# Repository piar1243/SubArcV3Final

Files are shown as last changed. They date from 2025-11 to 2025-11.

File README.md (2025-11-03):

Welcome to the repository for SubArc: An Inexpensive, High Resolution, Open Source, Absolute Magnetic Rotary Encoder!

In this repository, there are the files for the 3D models of the most recent SubArc PCB and Calibration Stand version. There are the SubArc python executable programs and the microcontroller (Arduino standard) code. Additionally, a specification sheet, a mounting tutorial, and other in-depth documentation are also listed.

At this time, SubArc is still under development. That being said, the current SubArc version does output 20 bit resolution at under 150 arc seconds of average accuracy, and can be vigilantly used for low-speed applications. 

The following improvements are being made to release an initial beta-version of SubArc (with the goal being by March 2026):

1) Fix occasional accuracy spike bugs
2) Increase position calibration file search algorithm efficiency
3) Increase sampling rate to 5000 Hz with updated hall sensor array
4) Create through-bore version for easy mounting on machinery

Once these improvements are made and SubArc properly functions embedded on precision machinery technology, SubArc will release into its V1 beta version and this repository will be linked and popularized.

If you would like to build your own alpha version SubArc and need assistance, or you would like to collaborate on speeding up the development to the initial V1 beta version, feel free to contact me at: franklucci636@gmail.com

This work is provisional-patent protected to ensure no one attempts to patent and close source this encoder. All current and future work will continue to be open source under the MIT license.

Current SubArc specification details:

You can customize the SubArc ring and readhead in your PCB software to change the resolution and accuracy

Standard resolution is 20-bits, with an 8mm bore, 55mm diameter, 100 magnets, and 6 hall sensors

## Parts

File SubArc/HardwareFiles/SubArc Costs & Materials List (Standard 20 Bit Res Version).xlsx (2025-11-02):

Materials |  | 1 UNIT IN <100 COST | TOTAL | 1 UNIT IN 100 COST | TOTAL | 1 UNIT IN 1000 COST | TOTAL | 1 UNIT IN 10000 COST | TOTAL | Calibration Stand Cost
1.25mm JST | 1 | $0.08 | $0.08 | $0.07 | $0.07 | $0.06 | $0.06 | $0.05 | $0.05 | RLS AksIM-2 E2019P Interface for SPI | $286.48
TMP117 | 1 | $1.91 | $1.91 | $1.58 | $1.58 | $1.39 | $1.39 | $1.28 | $1.28 | RLS AksIM-2 Encoder Readhead | $205.81
MLX90393SLW-ABA | 6 | $1.65 | $9.90 | $1.60 | $9.60 | $1.42 | $8.52 | $1.32 | $7.90 | RLS AksIM-2 Encoder Magnetic Ring | $212.91
1.25mm JST female | 1 | $0.41 | $0.41 | $0.29 | $0.29 | $0.25 | $0.25 | $0.21 | $0.21 | RLS aksIM-2 Absolute Magnetic Encoder ACC049 Cable Assembly | $13.02
PCB Way 10pc 100*100mm | 1 | $0.50 | $0.50 | $0.50 | $0.50 | $0.50 | $0.50 | $0.50 | $0.50 | Polylactic acid (PLA) filament 1kg | $18.99
1206 3.2*1.6mm SMD LED | 1 | $0.04 | $0.04 | $0.04 | $0.04 | $0.04 | $0.04 | $0.04 | $0.04 | DM542T Stepper Driver | $28.99
Samsung CAP CER 0.1UF 10V 0402 | 13 | $0.01 | $0.07 | $0.003 | $0.04 | $0.0025 | $0.03 | $0.0025 | $0.03 | M2-6 Threaded Heated Inserts & Screws <$10 | $10
RES 10K Ω 1/16W 0402 | 21 | $0.01 | $0.27 | $0.00408 | $0.09 | $0.00152 | $0.03 | $0.00134 | $0.03 | 2A, 48mm Nema 17 Stepper Motor | $13.99
CAP CER 10UF 10V 0805 | 1 | $0.04 | $0.04 | $0.03 | $0.03 | $0.03 | $0.03 | $0.02 | $0.02 | 100:1 Gearbox, 20 arc-min Backlash | $62.00
TI TCA9548APWR | 1 | $0.85 | $0.85 | $0.68 | $0.68 | $0.59 | $0.59 | $0.54 | $0.54 | ESP32 Microcontroller | $9.99
2pc 8mm flange coupling | 1 | $4.09 | $4.09 | $2 | $2 | $2 | $2 | $2 | $2 | 8*150mm h8 tolerance steel shafts | $8.99
1/32in N52 magnet (200pc) | 1 | $3.60 | $3.60 | $2.52 | $2.52 | $2.52 | $2.52 | $2.52 | $2.52 | 8mm ⌀ precision rigid clamp on coupling | $9.99
 |  |  | 0 |  | 0 |  | 0 |  | 0 | 20mm M4 standoff | $6.99
10pc jumper wire | 1 | $0.59 | $0.59 | $0.59 | $0.59 | $0.59 | $0.59 | $0.59 | $0.59 | 4pc F698ZZ 8mm Bore Flange bearing | $7.99
AS5600 Subdivider | 1 | $2.50 | $2.50 | $2.04 | $2.04 | $1.55 | $1.55 | $1.46 | $1.46 |  | $896.14
Total (Inexpensive Encoder): |  |  | $24.84 |  | $20.05 |  | $18.09 |  | $17.16
Magnetic Ring

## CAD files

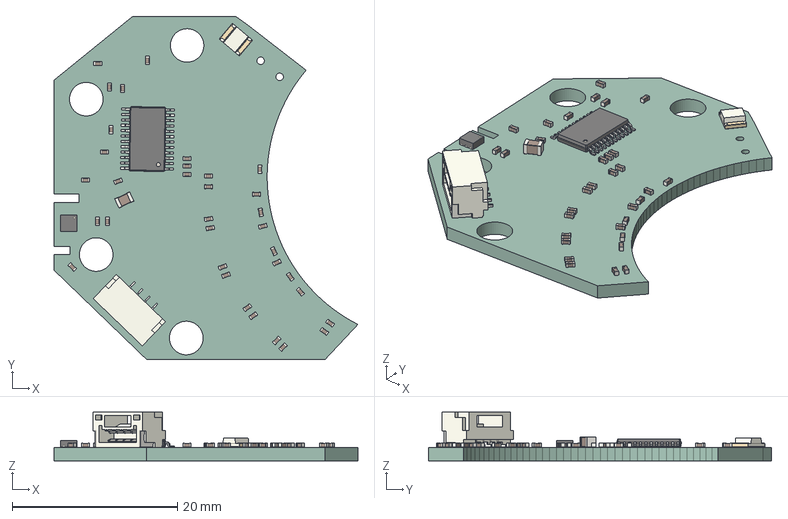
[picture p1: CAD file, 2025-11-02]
SubArc/HardwareFiles/SubArc&CalibrationStandCAD/SubArcModel.step
36.8 x 41.5 x 5.89 mm
C_0402_1005Metric_1 x 34
WSON_6_1EP_2x2mm_P065mm_EP1x16mm
JST_SM04B_GHS_TB
C_0805_2012Metric_1
TSSOP_24_44x78mm_P065mm
LED_1210_3225Metric_1
_autosave-SubArcV3 PCB

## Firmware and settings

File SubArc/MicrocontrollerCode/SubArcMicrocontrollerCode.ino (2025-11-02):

 #include <Wire.h>
#include "Adafruit_MLX90393.h"
#define stepPin 6 //defined arduino pins for rotating calibration stand stepper motor
#define dirPin 7
Adafruit_MLX90393 sensor = Adafruit_MLX90393();//uses adafruit MLX90393 sensor library to pull magnetic field readings from each sensor
#define MLX90393_CS 10 //cs pin on arduino
#include <Adafruit_TMP117.h> //uses the adafruit TMP117 sensor library and the adafruit sensor library
#include <Adafruit_Sensor.h>

Adafruit_TMP117  tmp117; //defines the tmp117 temperature sensor
double temper = 0;
int ill = 101;
String t_holder = "[24.5]"; //temperatures
String e_holder = "[0.1]";

float mag1 = 0;
float mag2 = 0;
int magnetStatus = 0; //magnet status of AS5600
 
int lowbyte; //AS5600 angle bits 7:0
word highbyte; //AS5600 angle bits 7:0 11:8
int rawAngle; //AS5600 angle out of 4096 (12 bits)
float degAngle; //AS5600 12 bit angle output out of 360

float mag_comp_val_x = 0;
float mag_comp_val_y = 0;
float mag_comp_val_z = 0;

float field_x_ca_val = 0;
float field_y_ca_val = 0;
float field_z_ca_val = 0;

void setup(void)
{
  pinMode(stepPin,OUTPUT); //activate pins
  pinMode(dirPin,OUTPUT);
  Serial.begin(115200); //begin serial

  Wire.begin(); //begin wire
  Wire.setClock(800000L); //set the clock cycle to the fastest possible cycle time


  TCA9548A(6); //switch to warmup
  
  while (!Serial) delay(10);  //will pause to wait for the Serial console to open

  if (!tmp117.begin()) { //initializes the TMP117 temperature sensor
    Serial.println("TMP117 disconnect");
    while (1) { delay(10); }
  }
  Serial.println("TMP117"); //printing to show that the sensor was intitialized

  
  
  TCA9548A(1); //switch to hall sensor 1
  Serial.println("active");

  while (!Serial) //wait for serial again to ensure no bugs
    delay(10);

   
  if (! sensor.begin_I2C(0x0c)) { //communicates to the standard MLX90393 (will change depending on which MLX90393 version you get)
    Serial.println("MLX90393 disconnect");
    while (1) { delay(10); }
  }
  Serial.println("MLX90393"); //indicates the MLX90393 has been activated and found
for (int i = 0; i < 6; i++){ //loops through all the different MLX90393 and defines their gain to the max, sets to max resolution, and most time effective and accurate sampling rate
  
  TCA9548A(i); //sets the multiplexer to the specific MLX90393 sensor
  
  sensor.setGain(MLX90393_GAIN_5X); //sets the MLX90393 gain to the max for best resolution
  // You can check the gain too
  Serial.print("Gain: ");
  switch (sensor.getGain()) { //defines the different gains available (pulled from the Adafruit libraries)
    case MLX90393_GAIN_1X: Serial.println("1 x"); break;
    case MLX90393_GAIN_1_33X: Serial.println("1.33 x"); break;
    case MLX90393_GAIN_1_67X: Serial.println("1.67 x"); break;
    case MLX90393_GAIN_2X: Serial.println("2 x"); break;
    case MLX90393_GAIN_2_5X: Serial.println("2.5 x"); break;
    case MLX90393_GAIN_3X: Serial.println("3 x"); break;
    case MLX90393_GAIN_4X: Serial.println("4 x"); break;
    case MLX90393_GAIN_5X: Serial.println("5 x"); break;
  }
.
  sensor.setResolution(MLX90393_X, MLX90393_RES_17); //sets the sensor resolution for each axis, goes to the max
  sensor.setResolution(MLX90393_Y, MLX90393_RES_17);
  sensor.setResolution(MLX90393_Z, MLX90393_RES_16);

  sensor.setOversampling(MLX90393_OSR_1); //sets oversampling rate to 1 so SubArc sampling time remains high

  sensor.setFilter(MLX90393_FILTER_5); //get the highest digital filter setting from MLX90393 for high accuracy at high resolution

}

}

void loop(void) {

  if (Serial.available() > 0) { //reads incoming byte from the python script
    char incomingByte = Serial.read();

  

  TCA9548A(6); //switches to the temperature sensor
  sensors_event_t temp; // create an empty event to be filled (from adafruit library)
  tmp117.getEvent(&temp); //fill the empty event object with the current measurements
  
  checkMagnetPresence(); //checks if the AS5600 is there, sends error if not
  ReadRawAngle(); //reads subdividing AS5600 position
  mag1 = degAngle; //sets the mag1 reading to the AS5600 position
   
  TCA9548A(5); // moves to the 5th MLX90393 (the Bexternal sensor)
  float x, y, z; //defines axis magnetic fields
   
  if (sensor.readData(&x, &y, &z)) {} //checks if sensor read data (from adafruit library)
  else {
    Serial.println("Unable to read XYZ data from the sensor.");
  }
  sensors_event_t event;
  sensor.getEvent(&event);
  mag_comp_val_x = event.magnetic.x; //sets the magnetic values to variables to subtract from regular MLX90393 readings
  mag_comp_val_y = event.magnetic.y;
  mag_comp_val_z = event.magnetic.z;
   
  
  for (int i = 0; i < 5; i++){ //loops through the MLX90393 array
    TCA9548A(i);
    float x, y, z; //defines the axis magnetic fields

    if (sensor.readData(&x, &y, &z)) {} //checks if sensor read data (from adafruit library)
    else {
        Serial.println("Unable to read XYZ data from the sensor.");
    }

    sensors_event_t event; // create an empty event to be filled (from adafruit library)
    sensor.getEvent(&event); //fill the empty event object with the current measurements
    Serial.print(String(i) + ", "); //print which hall sensor in the array your on in serial
    //Serial.print("X: "); 
  // Serial.print("["); 
  //all these values are picked up by python script when activited in the Serial communication protocol
    Serial.print(trun(int(event.magnetic.x - mag_comp_val_x + field_x_ca_val))); //prints the true X axis magnetic field for that hall sensor in the array
    Serial.print(", "); 
    Serial.print(int(trun(event.magnetic.y - mag_comp_val_y + field_y_ca_val))); //prints the true Y axis magnetic field for that hall sensor in the array
    Serial.print(", "); 
    Serial.print(int(trun(event.magnetic.z - mag_comp_val_z + field_z_ca_val))); //prints the true Z axis magnetic field for that hall sensor in the array
    Serial.print(", "); 

  // Serial.print("]");
    if (i < 4){
  //  Serial.print(", "); 
    }
  //Serial.println(temper);

    
  }
   
  // Serial.print("]");
 //  Serial.print("]");
 //  Serial.println("]");
   //Serial.println();
  Serial.print(degAngle); // prints the AS5600 angle
  Serial.print(", "); //adds the , because the data needs to be formatted correctly for the python script
  Serial.println(temp.temperature); //finally adds the temperature add the end of the string

if (incomingByte == 'b'){ //backwards stepper increment is B sending from the python script

   digitalWrite(dirPin, LOW);
   digitalWrite(stepPin,HIGH); 
   delayMicroseconds(20000);
   digitalWrite(stepPin,LOW); 
   delayMicroseconds(20000);

  
}

if (incomingByte == 'c'){ //forwards stepper increment is C sending from the python script

   digitalWrite(dirPin, HIGH);
   digitalWrite(dirPin, HIGH);
   digitalWrite(stepPin,HIGH);    
   delayMicroseconds(20000);
   digitalWrite(stepPin,LOW); 
   delayMicroseconds(20000);

  
}
}
}

void TCA9548A(uint8_t bus) //function to switch the sensors with the same I2C going to the multiplexer, function from adafruit
{
  Wire.beginTransmission(0x70); //TCA9548A address is 0x70
  Wire.write(1 << bus); //sending byte selects the number bus
  Wire.endTransmission();
}

int trun(int number) { //truncate function
    return (number / 10);
}


void ReadRawAngle() //reads the raw angle from the AS5600 (library function from curious scientist as5600 tutorial)
{ 

  Wire.beginTransmission(0x36); //connect to the sensor
  Wire.write(0x0D); //figure 21 - register map: Raw angle (7:0)
  Wire.endTransmission(); //end transmission
  Wire.requestFrom(0x36, 1); //request from the sensor
  
  while(Wire.available() == 0); //wait until it becomes available 
  lowbyte = Wire.read(); //Reading the data after the request
 
  Wire.beginTransmission(0x36);
  Wire.write(0x0C);
  Wire.endTransmission();
  Wire.requestFrom(0x36, 1);
  while(Wire.available() == 0);  
  highbyte = Wire.read();
  highbyte = highbyte << 8; //shifting to left
  rawAngle = highbyte | lowbyte; //int is 16 bits (as well as the word)
  degAngle = rawAngle * 0.087890625; 
}

void checkMagnetPresence(){ //checks the magnetic presence of the AS5600 (library function from curious scientist as5600 tutorial)
  while((magnetStatus & 32) != 32) //while the magnet is not adjusted to the proper distance - 32: MD = 1
  {
    magnetStatus = 0; //reset reading
    Wire.beginTransmission(0x36); //connect to the sensor
    Wire.write(0x0B); //figure 21 - register map: Status: MD ML MH
    Wire.endTransmission(); //end transmission
    Wire.requestFrom(0x36, 1); //request from the sensor
    while(Wire.available() == 0); //wait until it becomes available 
    magnetStatus = Wire.read(); //Reading the data after the request
    Serial.println(magnetStatus, BIN);
  }      
}

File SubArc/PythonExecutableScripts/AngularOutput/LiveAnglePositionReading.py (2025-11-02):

import ast
import serial
import time
import statistics

angular_position_error_log_file = "[file name for angular position error logging].txt"
final_position_calibration_file = "[file name for provided/created position calibration file].txt"
final_temperature_calibration_file = "[file name for provided/created temperature calibration file].txt"

aksim2_serial = serial.Serial('COM18', 9600, timeout=2)  # initializes communication w/ AksIM-2 calibration encoder
SubArcV3_Serial = serial.Serial(port='COM4',baudrate=115200)  # initializes communication w/ SubArc calibration encoder

#for the SubArc protocol, b is for incrementing 1 tick backwards and read I2C data
#for the SubArc protocol, c is for incrementing 1 tick forward and read I2C data

#ASCII Commands for AksIM-2 initialization & angle reading
#----------------------------------------------------------------------------------------------------------------------

ascii_1 = "v"  # checks for E201 presence
ascii_2 = "r"  # returns the serial number
ascii_3 = "V5"  # selects 5v power
ascii_4 = "n"  # turns on the encoder with 5v power
ascii_5 = "e"  # checks current
ascii_6 = "Ce"  # enables EncoLink
ascii_7 = "G0:1"  # initializes SCK
ascii_8 = "D015"  # initializes CS
# the sck and cs get sent as one complete command to the AksIM-2
ascii_9 = "M5"  # sets clock frequency
ascii_10 = "m"  # verifies selected clock frequency
ascii_11 = "j"  # initializes EncoLink (AksIM-2 communication protocol)

aksim2_angle_read_ascii = "?04:000"  # reads position bytes from the encoder

aksim2_initialization_list = ["v", "r", "V5", "n", "e", "Ce", "G0:1" "D015", "M5", "M5", "m", "j"]

#Angle determining code variables
#-----------------------------------------------------------------------------------------------------------------------
counter = 0
angle = 0
angle_second = 0
angle_third = 0
angle_fourth = 0
temperature = 24.5
data_list = []
#-----------------------------------------------------------------------------------------------------------------------

#Debugging for when SubArc data won't come through----------------------------------------------------------------------
input_list_1 = [-1065, 91, 1135, -895, 633, -2258, 258, 28, -588,
                -1309, 206, 3228, 801, -437, 1782, 75, 22, 91422.2]
input_list_2 = [-102, 232, 1344, -1019, 136, -1089, 1315, -217, -1568,
                -86, 39, -2902, 1008, -18, 2848, 69, 22, 112014.8]
input_list_3 = [-342, 48, -500, 1348, 65, -252, 302, 345, 1389,
                -782, -339, -2788, -1809, -145, -778, 85.25, 23.59, 63486.2]
input_list_4 = [-681, 11, -1072, 1332, 355, 98, -638, 132, 1921,
                326, -72, -2141, -991, -372, -1107, 81.65, 23.78, 74113.0]
input_list_5 = [-775, 268, -1494, 1040, 507, -258, -31, -117, 2268,
                -1782, 205, -2204, -861, -384, 387, 78.31, 23.77, 83804.8]
input_list_6 = [-993, 792, -814, 804, 332, -1422, 297, 481, 1619,
                -1258, -367, -843, -1017, -152, 2137, 89.38, 23.25, 51329.0]
input_list_7 = [-116, 245, -1653, 1248, 272, 872, -339, -295, 548,
                -349, 373, 2737, -595, -220, -212, 70.93, 23.45, 105652.8]
#----------------------------------------------------------------------------------------------------------------------


def aksim2_initialization():  # function to initialize the AksIM-2

    for j, command in enumerate(aksim2_initialization_list):  # loops through aksim_2 initialization asciis
        aksim2_serial.write(command.encode())  # writes the ascii command to the AksIM-2
        response = aksim2_serial.read(aksim2_serial.in_waiting)  # reads the AksIM-2 serial response
        print("response", response.decode())  # for each response, print the readable value
        time.sleep(0.1)  # ensure system isn't overloaded with sufficient time space between initializations


aksim2_initialization()  # run the aksim2 initialization


def aksim2_read_angle():  # function to read the AksIM-2 angle now that its initialized

    aksim2_serial.flushInput()  # flush input to ensure only new data enters the AksIM-2
    aksim2_serial.write(aksim2_angle_read_ascii.encode())  # writes request for position bits
    aksim2_serial.flushOutput()  # flushes output to ensure no extra corrupted data is sent with position
    time.sleep(0.01)  # spaces ensuring no overload
    response1 = aksim2_serial.read(aksim2_serial.in_waiting)  # reads the first bits
    #print(response1.decode()) #debugging

    binary_value = bin(int(response1, 16))[2:].zfill(32)
    # converts to integer, then binary, cleans line and adds zeros to front to make the value to 32 bit position

    first_20_bits = binary_value[:20]  # gets the 20 bit encoder data of the binary AksIM-2 position value

    decimal_value = int(first_20_bits, 2)  # converts the 20 bit binary into an integer position number

    #print("Binary value:", binary_value) #debugging
    #print("First 20 bits:", first_20_bits) #debugging
    #print("Decimal value of first 20 bits:", decimal_value) #debugging

    angular_value = decimal_value/1048576 * 360  # use this value if wanting to visualize AksIM-2 angular position
    time.sleep(0.01)  # delay slightly to ensure no overloading
    return decimal_value  # returns that AksIM-2 integer position value


def read_average_angle():  # averages the angle of the AksIM-2 input into the calibration file to make it more accurate
    average_angle = 0  # sets the averaging variable to 0 initially
    for k in range(5):
        average_angle += aksim2_read_angle()  # reads AksIM-2 angle 5 times, adds each value to the averaging variable
    print(average_angle/5)  # prints out the average AksIM-2 position for that specific stepper motor increment
    return average_angle/5  # returns accurate AksIM-2 position be logged in the calibration file

#initialize file


with open(final_position_calibration_file, 'r') as infile:  # opens position calibration file

    for line in infile:
        line = line.strip()  # takes all spaces out of formated file
        if line:
            try:
                data_list.append((ast.literal_eval(line))[0][0])  # strips away any extra cover lists
            except (SyntaxError, ValueError) as e:  # passes through the blank lines
                pass
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
